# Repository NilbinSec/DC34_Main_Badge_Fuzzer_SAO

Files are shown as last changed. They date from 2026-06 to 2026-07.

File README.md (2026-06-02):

# DC34_Main_Badge_Fuzzer_SAO
NilbinSec SAO for the DC34 Conference Badge that serves as a fuzzing tool for potential badge challenges.

This SAO is designed as a tool for hackers who want a quick way to fuzz specific parts of the DEF CON 34 main conference badge based on the initial information DEF CON released about the badge prior to the conference. This may be insanely useful, or may be completely useless in solving the annual badge challenge. Moreover, Mode 1 may harm your badge depending on how the badge designer has set up the GPIO pins.

# Modes
The Fuzzer SAO has 3 modes with the initial firmware:

Mode 1: Attack button cycles through GPIO1/2 on the left badge port attempting to interface/trigger the actions active on the pull-up/pull-downs on the GPIO pins for the main board.

Mode 2: Attack button triggers the open-drain wake-up interrupt to the CPU on GPIO4 (right SAO port)

Mode 3: Attack button reports as a slave i2c interface and listens for a response from the badge CPU to identify I2C addresses the badge is interested in by incrementally cycling through I2C addresses 0x00 - 0x7F

# Usage
Mode is set via the left momentary switch (mode select). Press the button the number of times of the mode you want. SAO will confirm by: M1 -- D1 Blink, M2 -- D2 Blink, M3 -- D3 Blink. In each case, the Mode LED light will remain solid afterward indicating the attack is ready. To trigger a mode, press the right momentary switch (Attack/Trigger)

There is a strong possibility that this badge will be able to be reflashed at the convention to solve additional issues/speed up solving badge challenges further into the badge challenge. We will likely release updated firmware.

# Flashing

Download firmware files. If you want to remake the firmware blob, the c file is included. You will need Zak Kemble's standalone AVR-GCC build from https://blog.zakkemble.net/avr-gcc-builds/ , the ATtiny series-1 device pack from http://packs.download.atmel.com/ (file Atmel.ATtiny_DFP.x.x.xxx.atpack — .atpack is just a renamed zip). Make sure both are on path for your CLI. 

To flash: "make flash PORT=COM5" (replace COM5 with your device's COM port)

# Repo Files

This repo includes base firmware, gerbers for the PCBs, schematic, and BOM file. Don't hesitate to reach out if you need something! 





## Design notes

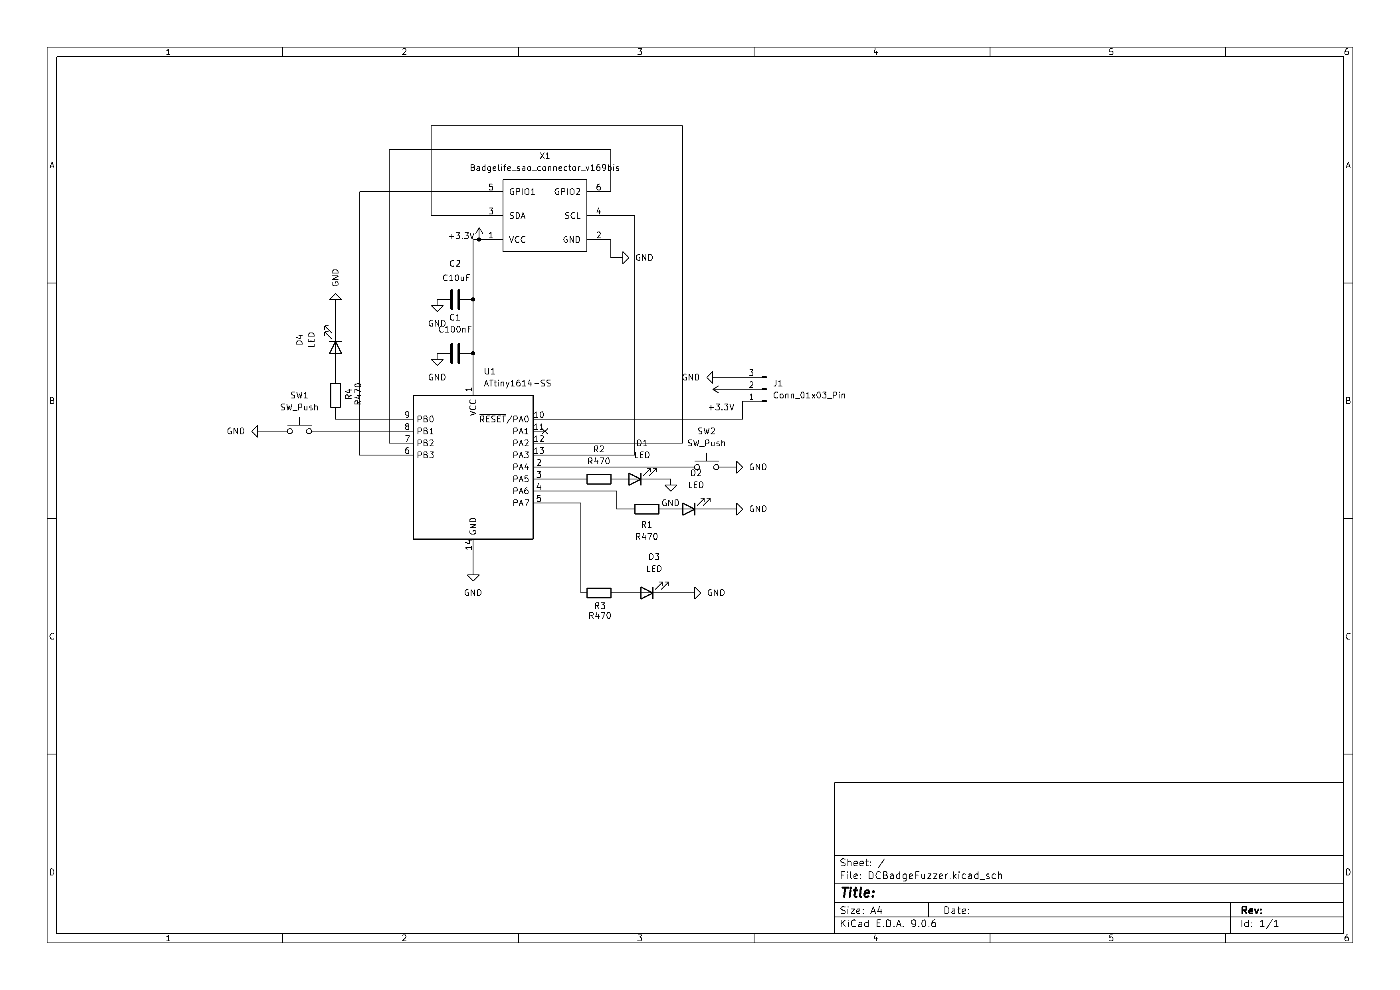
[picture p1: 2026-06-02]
image.png

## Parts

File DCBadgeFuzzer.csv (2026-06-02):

Reference | Value | Datasheet | Footprint | Qty | DNP
C1 | C100nF | ~ | Capacitor_SMD:C_0805_2012Metric_Pad1.18x1.45mm_HandSolder | 1
C2 | C10uF | ~ | Capacitor_SMD:C_0805_2012Metric_Pad1.18x1.45mm_HandSolder | 1
D1,D2,D3,D4 | LED | ~ | LED_SMD:LED_1206_3216Metric_Pad1.42x1.75mm_HandSolder | 4
J1 | Conn_01x03_Pin | ~ | Connector_PinSocket_2.54mm:PinSocket_1x03_P2.54mm_Vertical | 1
R1,R2,R3,R4 | R470 | ~ | Resistor_SMD:R_0805_2012Metric_Pad1.20x1.40mm_HandSolder | 4
SW1,SW2 | SW_Push | ~ | Badgelife Library:SW_TS04-66-85-BK-160-SMT | 2
U1 | ATtiny1614-SS | http://ww1.microchip.com/downloads/en/DeviceDoc/ATtiny1614-data-sheet-40001995A.pdf | Package_SO:SOIC-14_3.9x8.7mm_P1.27mm | 1
X1 | Badgelife_sao_connector_v169bis |  | Badgelife_SAO_v169bis_111:Badgelife-SAOv169-SAO-2x3 | 1

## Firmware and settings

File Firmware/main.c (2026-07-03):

/*
 * DC34 DEF CON Badge Fuzzer SAO  -- firmware
 * MCU: ATtiny1614-SSN  (UPDI on PA0, SerialUPDI programmer)
 * Tool: avr-gcc + avr-libc, -mmcu=attiny1614
 *
 * Modes (selected by SW1 multi-press inside a 350 ms window):
 *   1x SW1 -> Mode 1 : GPIO1/2 stimulus + response sampling   (left port)
 *   2x SW1 -> Mode 2 : GPIO4 open-drain wake assert           (right port)
 *   3x SW1 -> Mode 3 : I2C slave-listen sweep 0x08..0x77
 *                      (skips 0x19 accel and 0x3C OLED)
 *
 * SW2 fires the currently armed attack.
 * Optional 9600 8N1 debug log on PA1 (USART0 TXD).
 */

#define F_CPU 10000000UL         /* 20 MHz osc / 2, set at boot (see clock_init) */

#include <avr/io.h>
#include <avr/interrupt.h>
#include <util/delay.h>
#include <stdint.h>
#include <stdbool.h>

/* --- PORTA pin masks --------------------------------------------------- */
#define PIN_TXD   PIN1_bm        /* PA1  USART0 TXD (optional debug)      */
#define PIN_SDA   PIN2_bm        /* PA2  TWI SDA  -> SAO pin 3            */
#define PIN_SCL   PIN3_bm        /* PA3  TWI SCL  -> SAO pin 4            */
#define PIN_SW2   PIN4_bm        /* PA4  attack trigger, active-LOW       */
#define PIN_ACT   PIN5_bm        /* PA5  green LED                        */
#define PIN_HIT   PIN6_bm        /* PA6  amber LED                        */
#define PIN_ERR   PIN7_bm        /* PA7  red   LED                        */

/* --- PORTB pin masks --------------------------------------------------- */
#define PIN_MODE  PIN0_bm        /* PB0  blue  LED                        */
#define PIN_SW1   PIN1_bm        /* PB1  mode-cycle, active-LOW           */
#define PIN_GPIO2 PIN2_bm        /* PB2  GPIO2 / GPIO4-OD  -> SAO pin 6   */
#define PIN_GPIO1 PIN3_bm        /* PB3  GPIO1 / GPIO3     -> SAO pin 5   */

/* --- Timing ------------------------------------------------------------ */
#define BLINK_MS        100u
#define MODE_WINDOW_MS  350u     /* multi-press detection window          */
#define M3_LISTEN_MS    75u      /* listen time per slave address         */

/* --- USART0 baud register for 9600 baud:
 * BAUD = (F_CPU * 64) / (16 * 9600)  = F_CPU * 4 / 9600.
 * At F_CPU = 10 MHz: 4166.67 -> use 4167.                                  */
#define UART_BAUD_REG   4167u

/* ====================================================================== */
/*  Globals                                                                */
/* ====================================================================== */
static volatile uint8_t g_mode = 1;

/* ====================================================================== */
/*  LED helpers                                                            */
/* ====================================================================== */
static inline void leds_off(void)
{
    PORTA.OUTCLR = PIN_ACT | PIN_HIT | PIN_ERR;
    PORTB.OUTCLR = PIN_MODE;
}

static void blink_n(volatile PORT_t *port, uint8_t pin, uint8_t n)
{
    for (uint8_t i = 0; i < n; i++) {
        port->OUTSET = pin;
        _delay_ms(BLINK_MS);
        port->OUTCLR = pin;
        _delay_ms(BLINK_MS);
    }
}

/* ====================================================================== */
/*  Debug UART  (PA1 / USART0 TXD)                                         */
/* ====================================================================== */
static void uart_init(void)
{
    PORTA.DIRSET = PIN_TXD;
    USART0.BAUD  = UART_BAUD_REG;
    USART0.CTRLB = USART_TXEN_bm;
}

static void uart_putc(char c)
{
    while (!(USART0.STATUS & USART_DREIF_bm))
        ;
    USART0.TXDATAL = (uint8_t)c;
}

static void uart_puts(const char *s)
{
    while (*s)
        uart_putc(*s++);
}

static void uart_hex8(uint8_t v)
{
    static const char hex[] = "0123456789ABCDEF";
    uart_putc(hex[v >> 4]);
    uart_putc(hex[v & 0x0F]);
}

/* ====================================================================== */
/*  Mode confirmation (called after SW1 selects a mode)                    */
/* ====================================================================== */
static void confirm_mode(uint8_t mode)
{
    leds_off();
    switch (mode) {
    case 1: blink_n(&PORTA, PIN_ACT, 1); break;
    case 2: blink_n(&PORTA, PIN_HIT, 2); break;
    case 3: blink_n(&PORTA, PIN_ERR, 3); break;
    default: break;
    }
    PORTB.OUTSET = PIN_MODE;     /* MODE steady once confirmed */

    uart_puts("MODE ");
    uart_putc('0' + mode);
    uart_puts("\r\n");
}

/* ====================================================================== */
/*  Mode 1 : GPIO1/2 stimulus + response sampling                          */
/* ====================================================================== */
/*
 * The badge has pull-ups (2.2 k .. 47 k) on GPIO1/GPIO2.  Baseline with
 * the SAO pins tristated should read HIGH on both lines.  We:
 *   1. drive each 2-bit pattern (00,01,10,11) briefly,
 *   2. release to Hi-Z and sample,
 *   3. log via UART if the sample deviates from the pull-up baseline,
 *   4. sit Hi-Z for ~1.5 s afterwards looking for badge-initiated edges.
 */
static void attack_mode1(void)
{
    PORTA.OUTSET = PIN_ACT;

    /* Both lines tristated -> read baseline */
    PORTB.DIRCLR = PIN_GPIO1 | PIN_GPIO2;
    PORTB.OUTCLR = PIN_GPIO1 | PIN_GPIO2;
    _delay_ms(2);
    uint8_t baseline = PORTB.IN & (PIN_GPIO1 | PIN_GPIO2);

    uart_puts("\r\n[M1] base=");
    uart_hex8(baseline);
    uart_puts("\r\n");

    /* 4 stimulus patterns x 4 repeats */
    static const uint8_t pat[4] = {
        0,
        PIN_GPIO1,
        PIN_GPIO2,
        PIN_GPIO1 | PIN_GPIO2,
    };

    for (uint8_t rep = 0; rep < 4; rep++) {
        for (uint8_t i = 0; i < 4; i++) {
            const uint8_t both = PIN_GPIO1 | PIN_GPIO2;

            /* Drive pattern */
            PORTB.OUT    = (PORTB.OUT & ~both) | (pat[i] & both);
            PORTB.DIRSET = both;
            _delay_ms(8);

            /* Release and settle */
            PORTB.DIRCLR = both;
            PORTB.OUTCLR = both;
            _delay_us(150);

            /* Sample */
            uint8_t s = PORTB.IN & both;
            if (s != baseline) {
                PORTA.OUTSET = PIN_HIT;
                uart_puts("[M1] resp pat=");
                uart_hex8(pat[i]);
                uart_puts(" s=");
                uart_hex8(s);
                uart_puts("\r\n");
                _delay_ms(40);
                PORTA.OUTCLR = PIN_HIT;
            }
            _delay_ms(15);
        }
    }

    /* Passive listen for ~1.5 s */
    uart_puts("[M1] listen\r\n");
    PORTB.DIRCLR = PIN_GPIO1 | PIN_GPIO2;
    uint8_t prev = PORTB.IN & (PIN_GPIO1 | PIN_GPIO2);
    for (uint16_t t = 0; t < 1500; t++) {
        uint8_t now = PORTB.IN & (PIN_GPIO1 | PIN_GPIO2);
        if (now != prev) {
            PORTA.OUTSET = PIN_HIT;
            uart_puts("[M1] edge ");
            uart_hex8(now);
            uart_puts("\r\n");
            _delay_ms(25);
            PORTA.OUTCLR = PIN_HIT;
            prev = now;
        }
        _delay_ms(1);
    }

    PORTA.OUTCLR = PIN_ACT;
    uart_puts("[M1] done\r\n");
}

/* ====================================================================== */
/*  Mode 2 : GPIO4 open-drain wake assert  (held while SW2 down)           */
/* ====================================================================== */
static void attack_mode2(void)
{
    uart_puts("\r\n[M2] WAKE assert\r\n");

    /* Drive PB2 LOW (open-drain assert).  Output bit pre-set to 0 so
     * enabling DIR drives the line low immediately. */
    PORTB.OUTCLR = PIN_GPIO2;
    PORTB.DIRSET = PIN_GPIO2;
    PORTA.OUTSET = PIN_ERR;      /* ERR solid while asserted */

    while (!(PORTA.IN & PIN_SW2))
        _delay_ms(1);

    /* Release -> tri-state */
    PORTB.DIRCLR = PIN_GPIO2;
    PORTA.OUTCLR = PIN_ERR;

    uart_puts("[M2] released\r\n");
}

/* ====================================================================== */
/*  Mode 3 : bit-banged I2C slave-listen sweep                             */
/* ====================================================================== */
/*
 * The ATtiny1614's hardware TWI0 peripheral is physically wired to
 * PB0 (SCL) / PB1 (SDA) only -- there is no PORTMUX route that lands
 * SCL on PA3, and tinyAVR does not implement TWI dual-mode.  Since the
 * SAO carries SDA on PA2 and SCL on PA3, we must snoop the bus in
 * software using pin-change interrupts.
 *
 * We never drive either line -- purely passive.  Because we don't ACK,
 * the master sees a NACK for our probed address, which is fine for
 * detection: we've already latched the address byte on SCL rising
 * edges by the time the ACK bit rolls around.
 *
 * Timing budget @ F_CPU = 10 MHz:
 *   ISR entry+body+exit ~ 5 us; 100 kHz SCL half-period is 5 us.
 *   Reliable up to 100 kHz standard-mode I2C.  400 kHz fast-mode may
 *   drop bits.  Most badges run at 100 kHz.
 *
 * Skip list: 0x19 (accel) and 0x3C (OLED) are real silicon on the
 * badge -- listening on those addresses would cause bus contention.
 */

#define BB_STATE_IDLE   0
#define BB_STATE_ADDR   1
#define BB_STATE_ACK    2

static volatile uint8_t  bb_state;
static volatile uint8_t  bb_shift;
static volatile uint8_t  bb_bits;
static volatile uint8_t  bb_target;
static volatile bool     bb_hit;

ISR(PORTA_PORT_vect)
{
    uint8_t flags = PORTA.INTFLAGS;
    uint8_t inp   = PORTA.IN;
    uint8_t scl   = inp & PIN_SCL;   /* PA3 */
    uint8_t sda   = inp & PIN_SDA;   /* PA2 */

    /* SDA edge while SCL high => START (falling) or STOP (rising) */
    if (flags & PIN_SDA) {
        if (scl) {
            if (!sda) {
                bb_state = BB_STATE_ADDR;
                bb_bits  = 0;
                bb_shift = 0;
            } else {
                bb_state = BB_STATE_IDLE;
            }
        }
    }

    /* SCL rising edge => sample SDA, shift into address register */
    if (flags & PIN_SCL) {
        if (bb_state == BB_STATE_ADDR) {
            bb_shift <<= 1;
            if (sda)
                bb_shift |= 1u;
            if (++bb_bits == 8) {
                if ((uint8_t)(bb_shift >> 1) == bb_target)
                    bb_hit = true;
                bb_state = BB_STATE_ACK;
            }
        }
    }

    PORTA.INTFLAGS = flags;      /* clear handled edges */
}

static bool bb_listen_as(uint8_t addr, uint16_t listen_ms)
{
    /* Both lines as passive inputs; badge bus pull-ups hold them high. */
    PORTA.DIRCLR = PIN_SDA | PIN_SCL;

    bb_target = addr;
    bb_hit    = false;
    bb_state  = BB_STATE_IDLE;
    bb_bits   = 0;
    bb_shift  = 0;

    PORTA.INTFLAGS = PIN_SDA | PIN_SCL;         /* clear stale flags */

    PORTA.PIN2CTRL = PORT_ISC_BOTHEDGES_gc;     /* SDA both edges     */
    PORTA.PIN3CTRL = PORT_ISC_RISING_gc;        /* SCL rising only    */

    sei();
    for (uint16_t t = 0; t < listen_ms && !bb_hit; t++)
        _delay_ms(1);
    cli();

    PORTA.PIN2CTRL = 0;
    PORTA.PIN3CTRL = 0;
    PORTA.INTFLAGS = PIN_SDA | PIN_SCL;

    return bb_hit;
}

static void attack_mode3(void)
{
    uart_puts("\r\n[M3] I2C bit-bang listen sweep\r\n");
    uint8_t hits = 0;

    for (uint8_t addr = 0x08; addr <= 0x77; addr++) {
        if (addr == 0x19 || addr == 0x3C)
            continue;            /* skip known badge devices */

        /* Rapid blink: ACT + MODE while sweeping */
        PORTA.OUTTGL = PIN_ACT;
        PORTB.OUTTGL = PIN_MODE;

        if (bb_listen_as(addr, M3_LISTEN_MS)) {
            PORTA.OUTSET = PIN_HIT;
            uart_puts("[M3] HIT 0x");
            uart_hex8(addr);
            uart_puts("\r\n");
            hits++;
            _delay_ms(150);
            PORTA.OUTCLR = PIN_HIT;
        }
    }

    PORTA.OUTCLR = PIN_ACT;
    PORTB.OUTSET = PIN_MODE;     /* restore steady MODE indicator */

    uart_puts("[M3] done hits=");
    uart_hex8(hits);
    uart_puts("\r\n");
}

/* ====================================================================== */
/*  SW1 multi-press handler                                                */
/* ====================================================================== */
/*
 * Entered after the first press has been debounced.  Wait for that first
 * release, then open a fixed MODE_WINDOW_MS window during which any
 * additional press increments the count (clamped to 3).
 */
static void handle_sw1(void)
{
    uint8_t presses = 1;

    /* Wait for the initial release. */
    while (!(PORTB.IN & PIN_SW1))
        ;
    _delay_ms(15);

    for (uint16_t t = 0; t < MODE_WINDOW_MS; t++) {
        _delay_ms(1);
        if (!(PORTB.IN & PIN_SW1)) {
            _delay_ms(15);
            if (!(PORTB.IN & PIN_SW1) && presses < 3) {
                presses++;
                while (!(PORTB.IN & PIN_SW1))
                    ;
                _delay_ms(15);
            }
        }
    }

    g_mode = presses;
    confirm_mode(g_mode);
}

/* ====================================================================== */
/*  Clock init                                                             */
/* ====================================================================== */
/*
 * Boot default: 20 MHz internal osc / 6 = 3.33 MHz.
 * We want 10 MHz (20 MHz / 2) for enough ISR headroom to snoop I2C in
 * Mode 3.  Writing MCLKCTRLB is CCP-protected.
 *
 * VCC = 3.0 V nominal on the badge; ATtiny1614 is spec'd for 10 MHz
 * down to 2.7 V, so this is inside envelope.
 */
static void clock_init(void)
{
    CCP = CCP_IOREG_gc;
    CLKCTRL.MCLKCTRLB = CLKCTRL_PDIV_2X_gc | CLKCTRL_PEN_bm;
}

/* ====================================================================== */
/*  Hardware init                                                          */
/* ====================================================================== */
static void hw_init(void)
{
    clock_init();

    /* LEDs as outputs, off */
    PORTA.DIRSET = PIN_ACT | PIN_HIT | PIN_ERR;
    PORTB.DIRSET = PIN_MODE;
    leds_off();

    /* Switches: input + internal pull-up */
    PORTA.PIN4CTRL = PORT_PULLUPEN_bm;       /* SW2 / PA4 */
    PORTB.PIN1CTRL = PORT_PULLUPEN_bm;       /* SW1 / PB1 */

    /* GPIO1 (PB3): output, idle low (will be retargeted as needed) */
    PORTB.OUTCLR = PIN_GPIO1;
    PORTB.DIRSET = PIN_GPIO1;

    /* GPIO2 (PB2): Hi-Z idle; pre-load OUT=0 so future DIRSET = open-drain
     * low assert with no glitch. */
    PORTB.OUTCLR = PIN_GPIO2;
    PORTB.DIRCLR = PIN_GPIO2;

    uart_init();
    uart_puts("\r\nDC34 SAO Fuzzer up\r\n");

    /* Power-on LED self-test */
    PORTA.OUTSET = PIN_ACT | PIN_HIT | PIN_ERR;
    PORTB.OUTSET = PIN_MODE;
    _delay_ms(200);
    leds_off();
    _delay_ms(100);

    confirm_mode(g_mode);
}

/* ====================================================================== */
/*  Main loop                                                              */
/* ====================================================================== */
int main(void)
{
    hw_init();

    for (;;) {
        /* SW1 -- mode cycle */
        if (!(PORTB.IN & PIN_SW1)) {
            _delay_ms(15);
            if (!(PORTB.IN & PIN_SW1))
                handle_sw1();
        }

        /* SW2 -- fire current attack */
        if (!(PORTA.IN & PIN_SW2)) {
            _delay_ms(15);
            if (!(PORTA.IN & PIN_SW2)) {
                /* Mode 2 acts while SW2 is held; modes 1/3 wait for release
                 * first so the user can let go before the run kicks off. */
                if (g_mode != 2) {
                    while (!(PORTA.IN & PIN_SW2))
                        ;
                    _delay_ms(15);
                }
                switch (g_mode) {
                case 1: attack_mode1(); break;
                case 2: attack_mode2(); break;
                case 3: attack_mode3(); break;
                default: break;
                }
            }
        }
    }
}
